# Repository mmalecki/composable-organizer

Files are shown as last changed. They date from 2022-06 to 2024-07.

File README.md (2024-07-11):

# Composable Organizer

**Archived:** The latching mechanism is not the best idea. I don't recommend anyone print this - just use Gridfinity.

Composable Organizer is a organizer system made up of compartments of various sizes
that can be joined together, as well as lids and trays.

The unit of sizing is one `u`, `1 u == 20 mm`.
The size of a container is identified by 3 numbers, each describing an axis.
For example `2 x 3 x 1` specifies a compartment of 40 mm x 60 mm x 20 mm outer size.

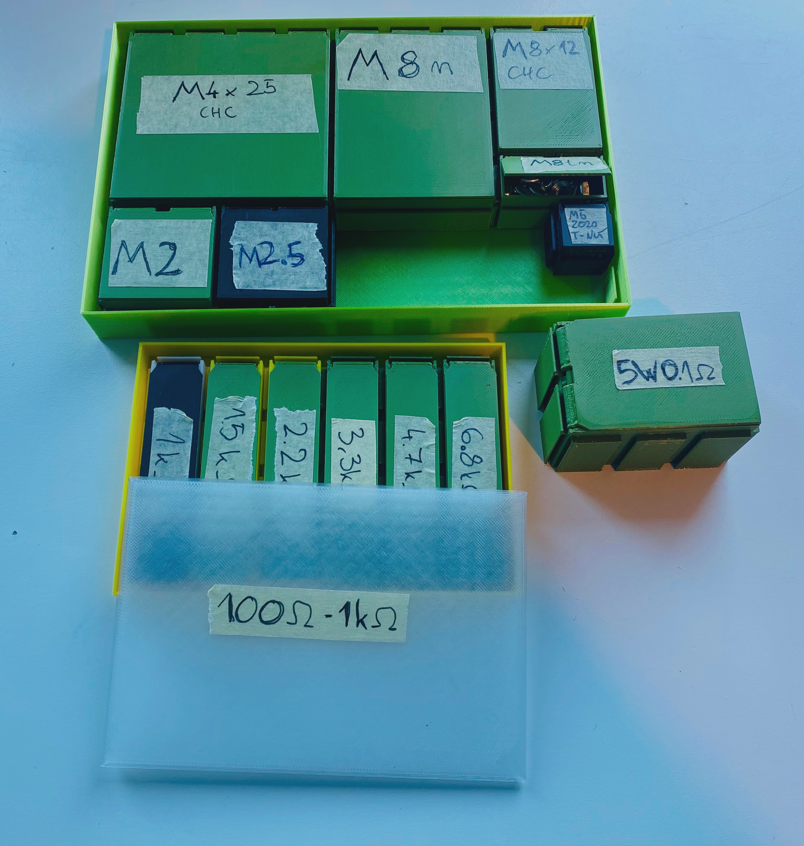
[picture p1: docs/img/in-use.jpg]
Compartments in use

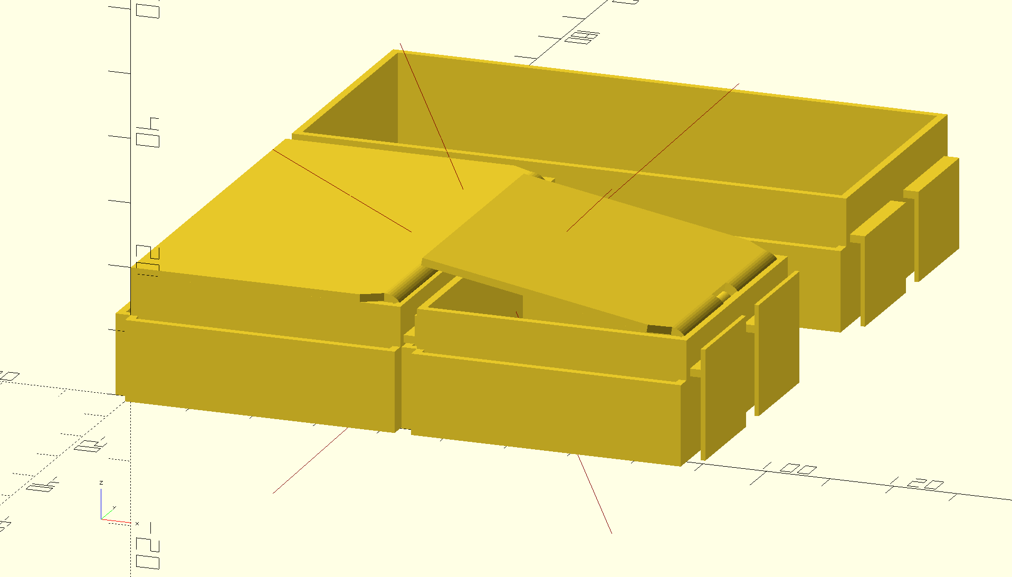
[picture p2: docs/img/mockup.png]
OpenSCAD render of some compartments


Wall thickness is 1.2 mm by default. It's adjustable, but containers of varying
wall thickness can't interface with each other.

## Build manual

### Quick build
To quickly print these out, head on over to [printables.com](https://www.printables.com/model/231583-composable-organizer). The 
model contains compartments, trays and lids STLs rendered for all variations of
sizes from 1u - 12u.

### Print settings
* **Material**: Any material. I used Prusament PLA.
* **Brim**: Do use brim for the compartments. The inserts can sometimes fall-over
  when thin walls (as by default) are used.
* **Layer height**: At most 0.2 mm layer height (recommend using [variable layer height](https://help.prusa3d.com/article/variable-layer-height-function_1750)
  with adaptive layer height, which will use different layer height for the
  base and the hinges).
* **Infill**: 15% (unless you customize wall thickness, most of the infill will be
  located inside the bottom wall).
* **Perimeters**: 3

### Building from source
If there's a particular size you need that isn't covered by the available STLs,
or you'd simply prefer to build the STLs from source, you can use OpenSCAD
and scripting inside this repository to do so:

```
git clone https://github.com/mmalecki/composable-organizer
cd composable-organizer
./scripts/build <size> # size in the format of `<x>x<y>x<z>`, e.g. `2x3x1`
# `output` directory will contain the built files.
```

(Note: the build script requires GNU Parallel.)

#### Customizing
The `parameters.scad` file contains several knobs you can tweak to get a more
custom system (e.g. with thicker walls).

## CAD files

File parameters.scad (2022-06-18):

press_fit = 0.05;
tight_fit = 0.1;
fit = 0.2;
loose_fit = 0.5;

// `u` - a single unit of size within our containers. Containers with the
// same `u` and `wall_t` can compose with each other.
u = 20;

// Wall thickness.
wall_t = 1.2; // Minimum thickness that makes sense with 0.4 mm FDM.

total_u = u + 2 * wall_t;

// Inserts:
insert_x_fit = loose_fit;
insert_y_fit = loose_fit;
hinge_u = 1.6; // Minimum "unit" that produces a sensible hinge with 0.4 mm FDM.
hinge_o_d = hinge_u * 4;
hinge_i_d = hinge_u * 2;
hinge_wall_t = (hinge_o_d - hinge_i_d) / 2;

// Hinge supports:
hinge_support_step = 20; // How often to place a support for the hinge. 
hinge_support_w = 3.2;
hinge_support_t = hinge_u;
hinge_rib_t = loose_fit;

lid_hinge_angle = 260;
lid_top_fit = tight_fit;

emboss_versions = false;
version_emboss_depth = wall_t / 3;
version_emboss_font_size = 3;
version_emboss_offset = wall_t;

// Tray:
//
// You may want more solid walls on your trays. The tray will still interface
// with `wall_t` compartments.
tray_wall_t = wall_t;
tray_lid_fit = press_fit;

// The fit here is larger because the tray is not the primary thing holding
// the containers together. Additionally, there's less clearance to take these
// fits apart, so we want to make that easier.
tray_insert_x_fit = loose_fit;
tray_insert_y_fit = 3;
// The fit between outside of the tray and compartments.
tray_fit = loose_fit;
tray_top_fit = tray_wall_t;
// The fit between compartments inside the tray.
tray_containers_fit = fit;

// Tray lid:
notch_h = tray_wall_t / 2;
notch_d = tray_wall_t;
notch_w = u / 2;
tray_lid_catch = 2.5 * tray_wall_t;

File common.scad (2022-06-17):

use <utils.scad>;
include <parameters.scad>;

module receptacle (o_y, h) {
  receptacle_d = 3 * wall_t;
  square_sleeve([receptacle_d, o_y, h], wall_t);
}

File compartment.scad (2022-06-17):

use <utils.scad>;
use <sizing.scad>;
use <common.scad>;
include <parameters.scad>;

module hinge_supports (i_y) {
  supports = floor(i_y / (hinge_support_step + hinge_support_w));
  if (supports > 0) {
    for (i = [1 : supports]) {
      translate([0, -hinge_support_w / 2 + i * hinge_support_step + (i - 1) * (2 * wall_t), 0])
        rotate([0, 135, 0])
          cube([hinge_support_t, hinge_support_w, sqrt(pow(hinge_o_d, 2) * 2) / 2]);
    }
  }
}

module hinge (i_y, o_z) {
  // Hinge bridge:
  translate([0, wall_t, o_z - hinge_i_d]) {
    rotate([270, 0, 0]) cylinder(d = hinge_i_d, h = i_y);
    hinge_supports(i_y);
  }

  // Ribs (in hopes of supporting the structure a little):
  translate([-hinge_i_d / 2, wall_t])
    cube([hinge_i_d, hinge_rib_t, o_z - wall_t]);
  translate([-hinge_i_d / 2, i_y + wall_t - hinge_rib_t])
    cube([hinge_i_d, hinge_rib_t, o_z - wall_t]);
}

module insert (o_z, bridge_h, lid_guard = false) {
  insert_w = u - 2 * wall_t - insert_y_fit;

  translate([0, insert_y_fit / 2]) {
    translate([0, 0, bridge_h]) cube([wall_t + insert_x_fit, insert_w, wall_t]);
    translate([wall_t + insert_x_fit, 0])
      cube([wall_t - insert_x_fit, insert_w, bridge_h + wall_t + (lid_guard ? hinge_i_d : 0)]);
  }
}

//
// Single compartment of given size in `u`.
//
module compartment (size, lid_hinge = false) {
  o_x = outer_x(size[0]);
  o_y = outer_y(size[1]);
  o_z = size[2] * u;

  i_x = o_x - 2 * wall_t;
  i_y = o_y - 2 * wall_t;
  // If the compartment has a lid hinge, add in a clearanace for that lid in
  // order to stay under `u * z` outer size.
  i_z = o_z - (lid_hinge ? 2 : 1) * wall_t;

  bridge_h = insert_bridge_h(o_z);

  // Bottom:
  difference () {
    cube([o_x, o_y, wall_t]);

    if (emboss_versions) {
      version_text();
    }
  }

  // Walls:
  translate([0, 0, wall_t]) {
    difference () {
      square_sleeve([o_x, o_y, i_z], wall_t);
      if (lid_hinge) {
        // Clear out space for the lid's hinge to rotate around in.
        translate([o_x - hinge_i_d, wall_t, i_z - hinge_i_d - hinge_wall_t])
          cube([hinge_i_d, o_y - 2 * wall_t, hinge_i_d + hinge_wall_t]);
      }
    }
  }

  translate([o_x, -2 * wall_t]) rotate([0, 0, 90]) receptacle(o_x, bridge_h - fit);
  translate([wall_t, o_y]) rotate([0, 0, 180]) receptacle(o_y, bridge_h - fit);

  for (j = [1 : floor(size[0])])
    translate([wall_t + total_u * (j - 1), o_y])
      rotate([0, 0, 270]) mirror([1, 0, 0])
        insert(o_z, bridge_h);

  for (i = [1 : floor(size[1])])
    translate([o_x, wall_t + total_u * (i - 1)]) insert(o_z, bridge_h, lid_guard = lid_hinge);

  if (lid_hinge) {
    to_hinge_x(o_x) hinge(i_y, o_z);
  }
}

if (!is_undef(size)) {
  compartment(size, true);
}

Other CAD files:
lid.scad
mockup.scad
sizing.scad
tray-lid.scad
tray.scad
utils.scad

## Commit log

2022-05-29 Implement a prototype of a 1x1x1 box
    [compartment.scad, parameters.scad, utils.scad]
2022-05-29 Mostly migrate to be size-agnostic
    [compartment.scad]
2022-05-31 True-size the containers
    Fix mating for containers other than 1, 1, 1.
    Add supports for the hinge shafts.
    Break the files up into parts.
    [compartment.scad, lid.scad, mockup.scad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]
2022-05-31 Add lid support cut-outs in the lid
    [compartment.scad, lid.scad, mockup.scad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]
2022-05-31 Fit the receptacle height
    [compartment.scad]
2022-05-31 Make the lid and compartment math work for x > 2
    [compartment.scad, lid.scad]
2022-05-31 Fix lid length calculations
    [lid.scad]
2022-05-31 Make the lid receptacle math less convulted
    [lid.scad]
2022-05-31 Fix the step counting for lid receptacles
    [lid.scad]
2022-05-31 Increase the hinge support thickness
    [compartment.scad, parameters.scad]
2022-05-31 Fix receptacle count calculation
    [lid.scad]
2022-05-31 Preview the lid print-ready
    [lid.scad]
2022-05-31 Add some comments, remove a unused variable
    [parameters.scad]
2022-05-31 Create ribs around the hinge to support the structure
    [compartment.scad, lid.scad, parameters.scad]
2022-06-01 Fix code comment
    [lid.scad]
2022-06-01 Keep the insert bridge height the same for lid-less compartments
    Extend their inner height to cover for the missing lid
    Clean up and comment `parameters.scad`.
    [compartment.scad, parameters.scad]
2022-06-01 Show lid-less container in `mockup.scad`
    Use `sizing.scad` functions.
    [mockup.scad]
2022-06-01 Clarify a code comment
    [compartment.scad]
2022-06-01 Change the lid's point of origin
    We used to use the side opposite to the hinge. Use the hinge instead -
    it makes more sense with regards to rotation having a reasonable effect,
    etc.
    [compartment.scad, lid.scad, mockup.scad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]
2022-06-01 Fix un-hinged compartments having hinge clearance
    [compartment.scad]
2022-06-07 Increase the size of the hinge support width
    The previous support did very little to actually, well, support.
    Increase by 1.2 mm.
    [parameters.scad]
2022-06-07 Remove a debug `echo`
    [compartment.scad]
2022-06-07 Make it easy to disable parts of mockups
    [mockup.scad]
2022-06-07 Enable embossing a version identifier
    [compartment.scad, lid.scad, parameters.scad]
2022-06-07 Disable version embossing by default
    [parameters.scad]
2022-06-07 Fix version rotation on the lid
    [lid.scad]
2022-06-07 DRY and move the version embossment
    [compartment.scad, lid.scad, parameters.scad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]
2022-06-07 Attempt a smaller lid hinge angle
    [parameters.scad]
2022-06-09 Revert "Attempt a smaller lid hinge angle"
    The holding angle wasn't enough when printed with resin.
    This reverts commit 8a4149289e20f5a28b0fcc7d2ff34eaa3cfd3fe5.
    [parameters.scad]
2022-06-11 Let the outside handle version string
    [utils.scad]
2022-06-17 Implement primitive trays and lids
    [common.scad, compartment.scad, mockup.scad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]
2022-06-17 Remove an unused function
    [tray.scad]
2022-06-17 Separate out the top clearance
    Add a lid notch, increase the catch height.
    [parameters.scad, tray-lid.scad, tray.scad]
2022-06-17 Make the notch truly conditional
    [tray-lid.scad]
2022-06-17 Emboss versions in trays
    Remove the hinge translate from the common version text function.
    Increase the font size.
    [lid.scad, parameters.scad, tray.scad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]
2022-06-17 Fix lid catch fit
    [tray-lid.scad]
2022-06-18 Change the tray lid fit to press
    The fit is on both sides, so a little tighter than usual is expected.
    [parameters.scad]
2022-06-18 Add a container top lid fit
    [lid.scad, parameters.scad]
2022-06-18 It was all true
    [mockup.scad]
2022-06-25 Ignore files rejected by Printables.com
2022-06-25 Add a printables.com link
